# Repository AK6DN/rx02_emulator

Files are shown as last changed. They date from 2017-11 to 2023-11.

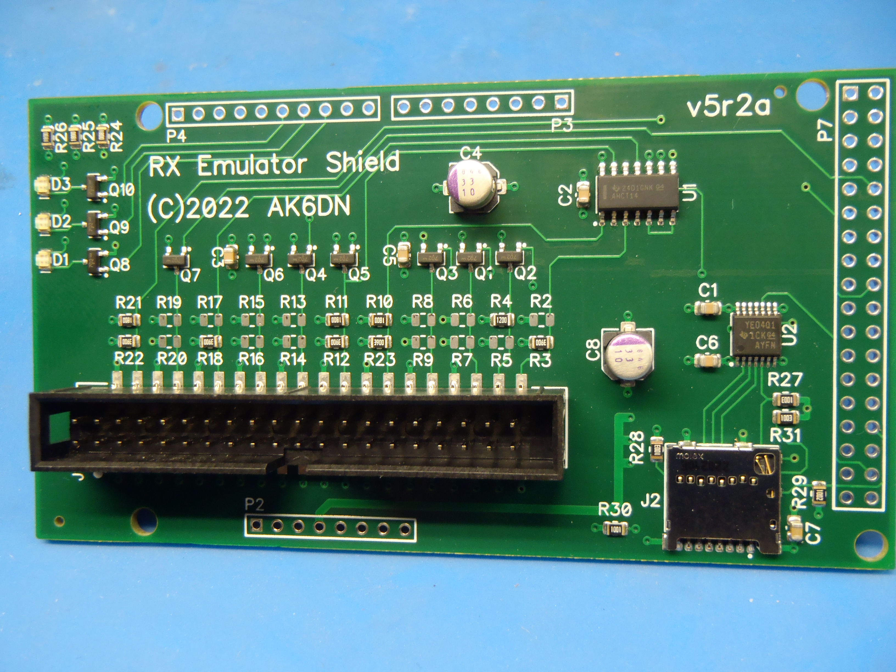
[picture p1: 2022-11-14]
documentation/pcb_v5_smt/rx02_emulator_pic.jpg

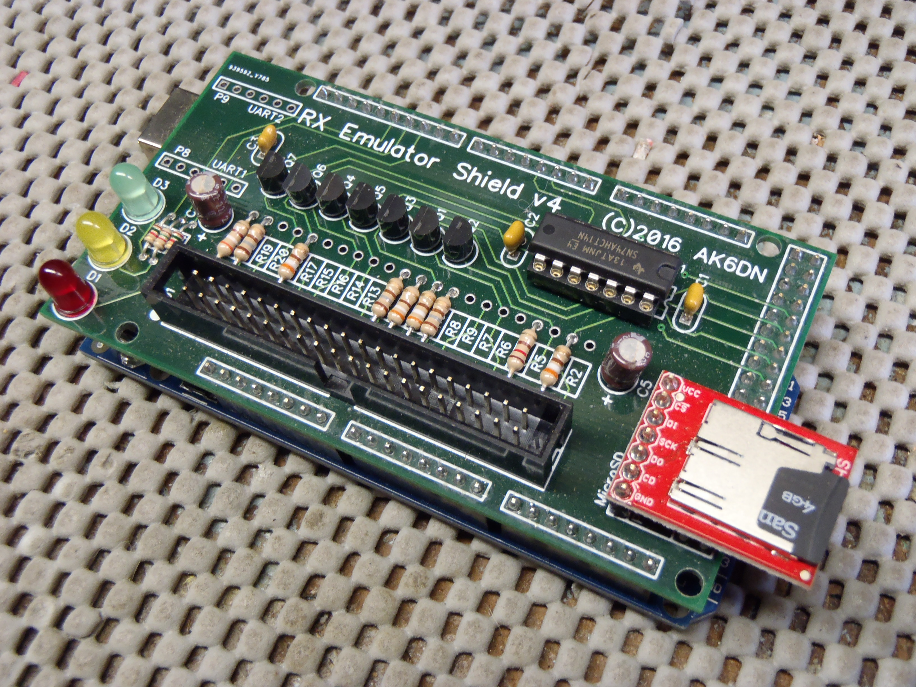
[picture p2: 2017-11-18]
documentation/pcb_v4_2n7k/rx02_emulator_pic.jpg

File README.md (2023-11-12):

# Overview #

`rx02_emulator` is a hardware/software emulation of a DEC RX02 (or RX01) dual 8" floppy disk drive. The software runs on an Arduino Mega2560 processor board with a custom hardware interface shield that maps a dozen or so digital port bits to the custom DEC RX drive interface protocol.

The emulator simulates two RX02/RX01 drives mapped to files on an attached MicroSD card.

This implementation was originally based on the design at:  http://www.chdickman.com/rx02/ but has been extensively modified for the Arduino and to provide the functionality necessary to pass the DEC RX02 hardware diagnostics.

Currently this design boots/runs under the PDP-11 XXDP and RT-11 operating systems and the PDP-8 OS/8 operating system.

The MicroSD card in the emulator is a FAT32 formatted filesystem, and it can be inserted (offline) into a WindowsPC to copy files to/from the device. By default, the files 'RX0.DSK' and 'RX1.DSK' are mapped to drive 0 and 1 on initialization.

Detection of single density media (256,256 bytes total) and double density media (512,512 bytes total) is done thru two differrent mechanisms. Files with the extension .RX1 will be forced to be single density, and resized appropriately (zero padded at the end, and truncated to size if required). Similarly files with the extension .RX2 will be forced to double density, and resized if necessary. Files with any other extension (ie, like .DSK) will be detected as single density if they are EXACTLY 256,256 bytes in size; and detected as double density if they are EXACTLY 512,512 bytes in size. Files that are other sizes will NOT be capable of being mounted until they are resized appropriately (the `E` and `F` commands can do this).

The emulator interfaces thru a simple ASCII terminal command line via the USB port on the Arduino device. After booting, typing: `H<cr>` types out the available commands. Below is a sample interaction showing the use of the `H`, `L`, `S` and `0` commands, and the debug level 1 log of what happens when `b dy0` is typed on the attached PDP-11/44 console terminal.

Startup configuration is saved in an ASCII text file SETUP.INI that contains user interface commands that are replayed on startup. The SETUP.INI file is written using the `W` command, and the current 0/1/Y/N/D/M/T options are saved in the file.

The hardware shield has three indicator LEDs:
<OL>
<LI>(RED) ON when INIT is asserted from the host or an error is detected in the emulator. OFF at command start.</LI>
<LI>(YEL) ON when the emulator is actively accessing the microSD card storage. OFF otherwise.</LI>
<LI>(GRN) ON when a command is inititated from the host, OFF when the command has completed (DONE set).</LI>
</OL>

Normal operation will see the GRN/YEL LEDs blinking rapidly or mostly ON. For non-storage commands (eg, buffer fill/empty) only GRN will be ON.

Hardware design files (schematics, PCB layout, BOM) are available in the documentation directory. Includes full schematic, PCB layout plots, and all gerbers.

The Arduino controller software has been moved into the source directory.

## Example ##

Sample boot log in the Arduino USB serial monitor window:
```
RX02 Emulator v2.02 (IDE 1.8.19/gcc 7.3.0) - Nov  3 2023 - 22:16:19
SD: libVersion=2.2.2
SD: cardType=SD3
SD: cardSize=3781MB
SD: volType=FAT32
SD: volBytesPerCluster=4096
SD: volClusterCount=964992
SD: volSizeBytes=3768MB
2016-09-24 18:02:14     512512 RX0.DSK
2016-09-27 15:06:44     512512 RX1.DSK
2020-04-01 00:00:26         50 SETUP.INI
2017-10-31 20:37:04     512512 RT11.RX2
2017-10-31 20:37:14     512512 OS8V3D.RX2
2016-10-24 11:31:02     256256 OS8V3Q.RX1
Valid MicroSD card detected.
RX: waiting for INIT to clear ... t=1154ms
RX: INIT has NOT cleared t=11155ms
RX: INIT rx_xmit_es(0244)

Processing setup file 'SETUP.INI' ...
0 RX0.DSK
Setting file[0]: 'RX0.DSK'
Y 0
Setting file[0] mode: R/W
1 RX1.DSK
Setting file[1]: 'RX1.DSK'
Y 1
Setting file[1] mode: R/W
D 1
Setting debug mode: 1 (Low)
M 2
Setting emulation mode: 2 (RX02+any)
T 0
Setting timing mode: 0 (Fastest)
S
Current file[0]: 'RX0.DSK' (R/W)
Current file[1]: 'RX1.DSK' (R/W)
... setup file processing complete!

Initialization complete.
H

Commands available:

  0 FILENAME    -- set unit 0 file to FILENAME; default RX0.DSK
                   file name 'none' (any case) for no disk present
  1 FILENAME    -- set unit 1 file to FILENAME; default RX1.DSK
                   file name 'none' (any case) for no disk present
  y(es) N       -- set unit N file read-write (default)
  n(o) N        -- set unit N file read-only
  m(ode) N      -- set emulation mode, 0=RX01+RX11, 1=RX01+RX8E, 2=RX02+any; default 2
  d(ebug) N     -- debug level, 0=none, 3=max; default 1
  t(iming) N    -- timing mode, 0=fast, 1=medium, 2=normal; default 0
                   0 as fast as possible; 2 simulates real RX02 drive
  r FILENAME    -- remove file FILENAME
  e FILENAME    -- extend/truncate file FILENAME to single density size
  f FILENAME    -- extend/truncate file FILENAME to double density size
  l(ist)        -- list all files on the SD card
  s(how)        -- show current unit filename assignments
  p(rint)       -- print full emulation state
  i(nit)        -- initialize emulator (like unibus INIT)
  k(ill)        -- kill the emulator (reset and restart, like reset button)
  w(rite)       -- write current configuration into the SETUP.INI file
  z(ap) STAMP   -- set current timestamp for file access
                   format is: YYYY-MM-DD HH:MM:SS or YYYY-MM-DD HH:MM
  h(elp)        -- display this text

Note: chars in () are optional. Case does not matter.

S
Current file[0]: 'RX0.DSK' (R/W)
Current file[1]: 'RX1.DSK' (R/W)
0 XXDP.DSK
Setting file[0]: 'XXDP.DSK'
W
Generating setup file 'SETUP.INI'

RX: waiting for INIT to clear ... t=49342ms
RX: INIT has cleared t=49438ms
RX: INIT rx_xmit_es(0244)

RX: cmd=0007
RX: RDSECT unit=0 den=S
RX: RDSECT sa=001
RX: RDSECT ta=001
RX: RDSECT rx_xmit_es(0060)

RX: waiting for INIT to clear ... t=49462ms
RX: INIT has cleared t=49557ms
RX: INIT rx_xmit_es(0244)

RX: cmd=0407
RX: RDSECT unit=0 den=D
RX: RDSECT sa=001
RX: RDSECT ta=001
RX: RDSECT pos=6656. len=256.
RX: RDSECT rx_xmit_es(0040)

RX: cmd=0403
RX: EMPBUF unit=0 den=D
RX: EMPBUF wc=200
RX: EMPBUF rx_xmit_es(0000)

RX: cmd=0407
RX: RDSECT unit=0 den=D
RX: RDSECT sa=003
RX: RDSECT ta=001
RX: RDSECT pos=7168. len=256.
RX: RDSECT rx_xmit_es(0040)

RX: cmd=0403
RX: EMPBUF unit=0 den=D
RX: EMPBUF wc=200
RX: EMPBUF rx_xmit_es(0000)

...
```

## Notes ##

(1) This code has been written with the assumption that `Xprintf` support has been added to the PRINT class in the Arduino development environment.

(2) This code uses the SDfat library available at:  https://github.com/greiman/SdFat

(3) This code was written with tap stops set at 4 (versus the default of 2). Manually edit the Arduino <B>preferences.txt</B> file tab size line to be: <B>editor.tabs.size=4</B> if desired.

# ALTERNATIVE to ARDUINO IDE #

For those not interested in the source and/or installing the full Arduino IDE environment and tweaking it as necessary, I have now added a precompiled .hex version of the code representing the state of the current source. It is located in the 'binary' folder. There are two versions, without and with the bootloader image present. In most cases you would want to use the version of the .hex without the bootloader as the bootloader is already present (and required to be working) in any purchased ArduinoMEGA2560 board.

There are at least two methods to download a .hex image file to the Arduino (and I am sure there are more):

(1) Using `avrdude` in command line mode. This is the way the Arduino IDE does it when you install the IDE and use it to download the compiled .hex file. You can use the installed version of avrdude to do the download, or alternatively if you don't want to install the full IDE and compile from source, you can download the avrdude program directly from here: https://github.com/avrdudes/avrdude 

On the command line:
```
  avrdude -D -cwiring -pm2560 -b115200 -PCOM# -Uflash:w:rx02_emulator.ino.hex:i
```
where `COM#` is the port that is associated with your mega2560 Arduino board, and other options that you may desire. Refer to the avrdude documentation.

(2) Using a program called `xLoader` that is available from here: https://github.com/binaryupdates/xLoader . It is a simple Windows standalone application. 

The process to download the .hex image using xLoader is documented here: https://www.aranacorp.com/en/generating-and-uploading-hex-files-to-an-arduino/ 

# INSTALLATION #

The following sections detail the installation and configuration of the Arduino software environment, getting the `rx02_emulator` code, compiling it, and downloading it to a target board.

## Arduino IDE ##

If you don't have the Arduino development environment installed on your system, the first step is to download and install it. Go to:

https://www.arduino.cc/

and click on the `Software` tab to get to the download page.

Scroll down to the `Download the Arduino IDELegacy IDE (1.8.X)` section and download the installer appropriate for your system. All development and testing to data has been with the legacy 1.X IDE. I have done nothing with the newer 2.X IDE, so if you want to use that you are on your own.

Update: I have installed the IDE 2.2.1 alongside my existing IDE 1.8.19. They live in separate directories so can be simultaneously installed. They share library and board file definitions, so I was able to launch IDE 2.2.1 and recompile and download the existing design done under IDE 1.8.19 with no errors. So the changes below for adding printf support and installing the SDFAT (and optional TIMELIB) libraries should take place following the existing instructions. One anomaly is after the compile the Arduino IDE version reported is IDE 1.6.7, when one might expect it to be IDE 2.2.1. This is a 'bug' reported in github and it appears the Arduino developers don't seem to feel it makes a difference and are reluctant to change it. So just be warned about the somewhat bogus report the program was compiled under IDE 1.6.7 when it appears in the compiled code welcome message.

Run the install.

## SD FAT Library ##

The emulator software requires a third party SD card FAT filesystem access library. Go to:

https://github.com/greiman/SdFat

On the right hand side of the page there is a `Clone or download` green button; click it and select `Download ZIP` and save the file. It will likely be named `SdFat-master.zip`.

Unzip the contents of `SdFat-master.zip` into a folder. There should be a folder inside the top level folder named `SdFat`.

Move the folder `SdFat` into your Arduino local library folder. On Windows, this would be into the folder:

```
C:\Users\yourname\My Documents\Arduino\libraries
```

which probably just contains a `readme.txt` file. The `SdFat` library is now installed and ready for use.

As of version v1.96 release the code is compatible with either the existing v1 SDfat library (eg, v1.1.4) or the newer v2 SDfat library (eg, v2.2.0) code.

I have tested with the v2.0.6, v2.0.7, v2.1.0, and v2.2.0 SDfat libraries. There were some changes from 2.0.x to 2.1.x and later and these are accounted for in some conditionals.

## PRINTF Configuration ##

The emulator code is written assuming that the printf/sprintf methods have been added to the serial I/O and file access routines. The default Arduino install does not have this support so it needs to be configured.

The following page:

http://playground.arduino.cc/Main/Printf

describes several ways to do this; the preferred method I suggest is described under `Adding printf() to Print class`.

It is not difficult, but does require editing a standard Arduino system file and adding some code.

On windows, the target file to be modified is:

```
%ProgramFiles(x86)%\Arduino\hardware\arduino\avr\cores\arduino\Print.h
```

the following code:

```
#include <stdarg.h>
#define PRINTF_BUF 80 // define the tmp buffer size (change if desired)
   void printf(const char *format, ...)
   {
   char buf[PRINTF_BUF];
   va_list ap;
        va_start(ap, format);
        vsnprintf(buf, sizeof(buf), format, ap);
        for(char *p = &buf[0]; *p; p++) // emulate cooked mode for newlines
        {
                if(*p == '\n')
                        write('\r');
                write(*p);
        }
        va_end(ap);
   }
#ifdef F // check to see if F() macro is available
   void printf(const __FlashStringHelper *format, ...)
   {
   char buf[PRINTF_BUF];
   va_list ap;
        va_start(ap, format);
#ifdef __AVR__
        vsnprintf_P(buf, sizeof(buf), (const char *)format, ap); // progmem for AVR
#else
        vsnprintf(buf, sizeof(buf), (const char *)format, ap); // for the rest of the world
#endif
        for(char *p = &buf[0]; *p; p++) // emulate cooked mode for newlines
        {
                if(*p == '\n')
                        write('\r');
                write(*p);
        }
        va_end(ap);
   }
#endif
```

needs to be added near the end of the file, just prior to the second to last non blank line:  `};`

NOTE this change must be made ANY TIME a new version of the Arduino IDE is installed, as the new install will overwrite the change to the `Print.h` file. In most recent Arduino upddates (since 1.6.X at least) the `Print.h` file has not changed, so a copy of the updated file can be squirreled away to save some time in the update process. Note that there was a minor change to the base `Print.h` file as of Arduino IDE 1.8.2 (this change should be integrated in the updated Print.h file as well).

At this point the Arduino IDE should be fully setup for use in compiling the emulator software.

Under the `Preferences` menu, I find ticking the `Show verbose output` `compilation` and `upload` boxes to be useful.

I also recommend checking the `Verify code after upload` box in the same dialog.

## RX02 Emulator ##

To download the RX02 emulator Arduino software, go to:

https://github.com/AK6DN/rx02_emulator

and (like in the library download) click the `Clone or download` green button on the right side of the page, select `Download ZIP`, and save the file. It will likely be named `rx02_emulator-master.zip`.

Unzip the contents into a folder, it will likely end up being named `rx02_emulator-master`. You must rename it to `rx02_emulator` as the Arduino IDE requires the outer level folder name match the project name (which is `rx02_emulator.ino`).

## Compiling ##

You should now be able to launch the Arduino IDE by going into the `source/rx02_emulator` folder and double clicking on the top level design file `rx02_emulator.ino`.

Before compiling you need to select the board and processor type.

Under the `Tools` menu select `Board:` and validate it is: `Arduino/Genuino Mega or Mega 2560`

Under the `Tools` menu select `Processor:` and validate it is: `ATmega2560`

You should now be able to, under the `Sketch` menu, select `Verify/Compile` (or type `CTRL-R`) to compile.

There should be no errors flagged if the SDfat library was installed correctly, the printf mod was performed, and the board and processor type have been configured correctly.

## Uploading ##

After verifying the compile you are now ready to be able to upload the code to your board.

NOW plug your Arduino Mega2560 board into a USB port on your system and wait for the USB driver to install.

When done, go to the `Tools` menu (again) and select the `Port:` entry to correspond to the USB serial port your board has been configured as.

You should now be able to select menu `Sketch` then `Upload` (or type `CTRL-U`) to upload the code to your board.

## Running ##

After a successful upload, your Arduino should start running immediately. To get access to the menu window, select under the `Tools` menu the `Serial Monitor` item (or type `CTRL-SHIFT-M`).

You will need to configure the baud rate / line ending of the monitor window before you can see output and type input.

In the lower right of the window, select the maximum baud rate `250000 baud` that the Arduino supports over USB. This minimizes the impact of the debug output window on performance, and the emulator software selects this rate by default. As of emulator code v1.8 and Arduino IDE 1.8.2 or later it is possible to enable higher debug window baud rates (500Kb, 1Mb, or 2Mb) but not all Arduino Mega2560 boards may support these rates 100% reliably. You will have to test your board individually to see if a higher baud rate can be enabled.

In the lower right, select `Carriage Return` line ending, so when you type in the text box at the top of the window, and then click `SEND` a `CR` character will be appended to the end of the string.

At this point you should be seeing debug output in the serial monitor window, and be able to send menu commands to it.

## Validation ##

Testing to date has been performed with a UNIBUS PDP-11/44 with each of an RX211 and an RX11, a UNIBUS PDP-11/34A with each of an RX211 and an RX11, and an OMNIBUS PDP-8m with an RX8E/RX28 so RX01/RX8E and RX02/RX28 configurations can be tested. I do not have access to RXV11 or RXV21 boards for testing (nor do I have an QBUS systems). Users have tested the emulator with QBUS RXV21 and RXV11 and provided positive feedback.

I have personally tested and validated the following confgurations:

```
PDP-11/44 with M8256 RX211 ... ZRXFB0 RX211/RX02 Functional Test  ........ PASS
                               ZRXDC0 RX211/RX02 Performance Exerciser ... PASS
                               XXDPv25 DY boots and runs ................. PASS
                               RT-11v5.7 DY boots and runs ............... PASS
                               RX02WR and RX02RD home grown diagnostics .. PASS

PDP-11/34A with M8256 RX211 .. ZRXFB0 RX211/RX02 Functional Test  ........ PASS
                               ZRXDC0 RX211/RX02 Performance Exerciser ... PASS
                               XXDPv25 DY boots and runs ................. PASS
                               RT-11v5.7 DY boots and runs ............... PASS
                               RX02WR and RX02RD home grown diagnostics .. PASS

PDP-11/44 with M7846 RX11 .... ZRXBF0 RX11/RX01 Functional Test .......... PASS
                               ZRXAF0 RX11/RX01 Performance Exerciser .... PASS
                               RT-11v5.3 DX boots and runs ............... PASS

PDP-11/34A with M7846 RX11 ... ZRXBF0 RX11/RX01 Functional Test .......... tbd
                               ZRXAF0 RX11/RX01 Performance Exerciser .... tbd
                               RT-11v5.3 DX boots and runs ............... tbd

PDP-8m with M8357 RX8E/RX01 .. OS8v3Q boots and runs ..................... PASS
                               RXTEST home grown diagnostic .............. PASS

PDP-8m with M8357 RX28/RX02 .. OS8v3D boots and runs ..................... PASS
                               RXTEST home grown diagnostic .............. PASS
```

Other users have supplied the following test results:

```
PDP-11/34 with M7846 RX11 .... ZRXBF0 RX11/RX01 Functional Test .......... PASS (thunter0512)
                               ZRXAF0 RX11/RX01 Performance Exerciser .... PASS (thunter0512)
```

## Hardware ##

UPDATED 09-Aug-2021 -- the timing macros for the data transfer to/from the interface board have been modified to allow working with a longer flat cable. As of the v1.95 release the emulator has been tested and worked flawlessly using a DEC BC06R-12 cable (12' long, about 4m) on a PDP-11/44 with an RX211 interface. Performance degradation due to the slightly slower data transfer handshake timing has been measured at about 5% or less, which in practice is not noticeable. Of course it still works flawlessly using a shorter 0.5 to 1.5m cable as well.

DEPRECATED 09-Aug-2021 -- Many original RX01/2 configurations come with an up to 5m controller card to connector cable (a 40p flat cable with 2x20p IDE connectors). It has been noticed that in some configurations using this same cable to connect to the RX02 emulator from the RXnn controller card results in unreliable operation or it does not work at all. The recommendation is to use a shorter 40p flat cable, on the order of 0.5m to 1.5m at most, for reliable operation.

## The End ##

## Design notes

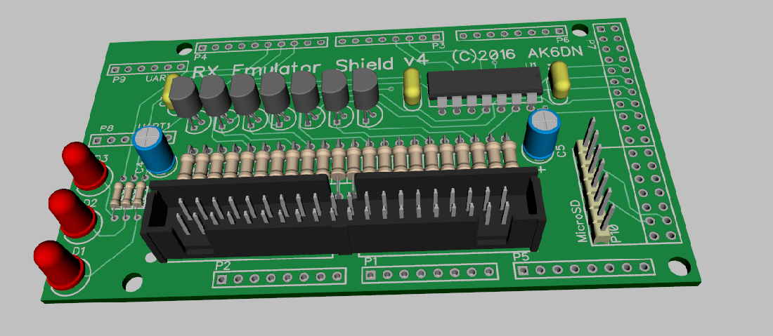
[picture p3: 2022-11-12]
documentation/pcb_v4_2n7k/rx02_emulator_3dv.png

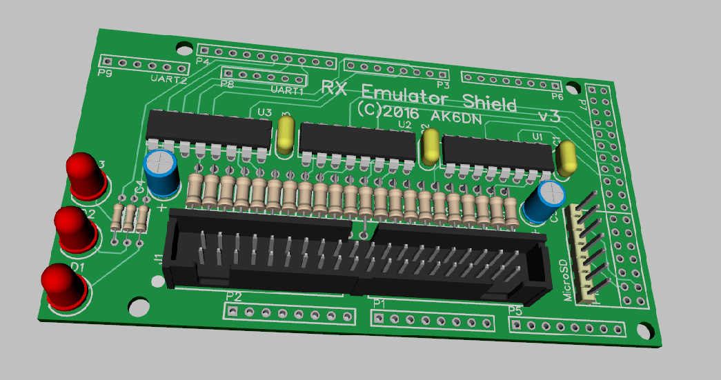
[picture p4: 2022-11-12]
documentation/pcb_v3_8641/rx02_emulator_3dv.png

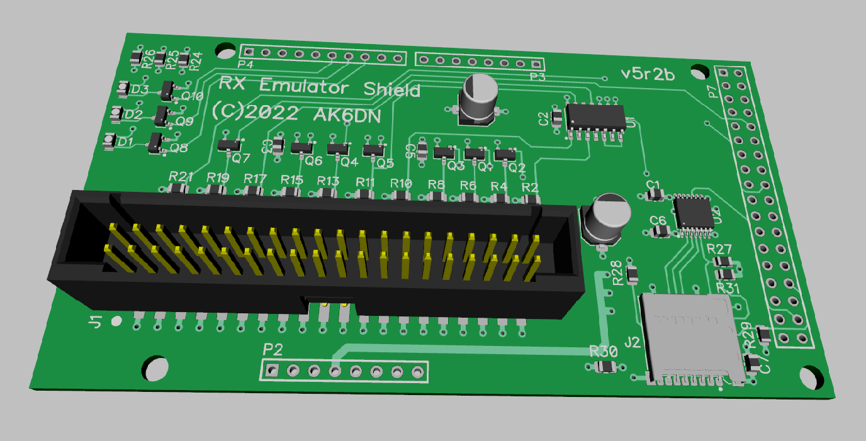
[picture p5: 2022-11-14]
documentation/pcb_v5_smt/rx02_emulator_3dv.png

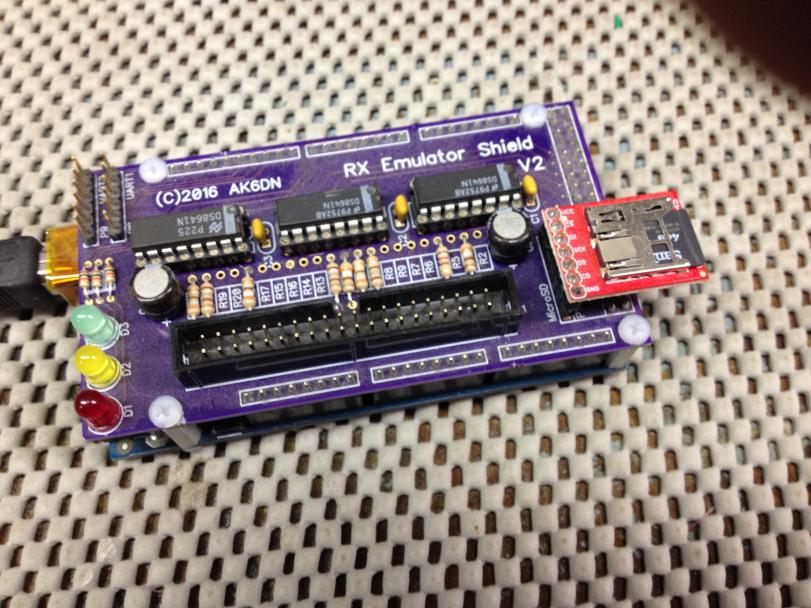
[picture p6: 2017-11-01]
documentation/pcb_v3_8641/rx02_emulator_pic.jpg

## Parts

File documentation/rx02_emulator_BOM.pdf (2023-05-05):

rx02_emulator_BOM

05/05/2023

Assembly Order | Quantity | Reference | Side | Note | Description | Manufacturer | ManufacturerPN | DigikeyPN
1 | 3 R24,R25,R26 | Top | - | 1Kohm,1/8W resistor (for 2mA LED current; value appropriate to LED) | Stackpole | CF18JT1K00 | CF18JT1K00CT-ND
2 | 5 R3,R12,R18,R22,R23 | Top | - | 390ohm,1/4W resistor | KOA Speer | CF1/4CT52R391J | 2019-CF1/4CT52R391JCT-ND
3 | 3 R10,R11,R21 | Top | - | 180ohm,1/4W resistor | KOA Speer | CF1/4CT52R181J | 2019-CF1/4CT52R181JCT-ND
4 | 1 R4 | Top | - | 120ohm,1/4W resistor | KOA Speer | CF1/4CT52R121J | 2019-CF1/4CT52R121JCT-ND
5 | 1 U1 | Top | - | 14p 300mil DIP socket | Assman | A 14-LC-TT | AE9989-ND
6 | 3 C1-C3 | Top | - | 100nF/16V ceramic capacitor, 100mil spacing | Vishay | K104K10X7RF53L2 | BC5137-ND
7 | 7 Q1-Q7 | Top | - | 2N7000 transistor, TO-92 package | Onsemi | 2N7000BU | 2N7000BU-ND
8 | 1 J1 | Top | - | 20x2P 100mil male box header | Sullins Connector | SBH11-PBPC-D20-ST-BK | S9175-ND
9 | 1 D1 | Top | - | LED, RED, 5mm diameter, 100mil spacing | Broadcom | HLMP-4700 | 516-1325-ND
10 | | 1 D2 | Top | - | LED, YEL, 5mm diameter, 100mil spacing | Broadcom | HLMP-4719 | 516-1326-ND
11 | | 1 D3 | Top | - | LED, GRN, 5mm diameter, 100mil spacing | Broadcom | HLMP-4740 | 516-1327-ND
12 | | 2 C4,C5 | Top | - | 33uF/16V electrolytic capacitor, radial, 100mil spacing, 6mm max diameter | Panasonic | ECE-A1CKS330 | P968-ND
13 | | 1 P4 | Bottom | - | 10x1P 100mil male header, 0.230/0.120 pin length, breakaway strip | Sullins Connector | PRPC040SAAN-RC | S1011EC-40-ND
14 | | 2 P2,P3 | Bottom | - | 8x1P 100mil male header, 0.230/0.120 pin length, breakaway strip | ref item 13 | - | -
15 | | 1 P7 | Bottom | - | 18x2P 100mil male header, 0.230/0.120 pin length, breakaway strip | Sullins Connector | PRPC018DAAN-RC | S2011EC-18-ND
16 | | 1 P10 | Top | - | 7x1P 100mil male header, 0.230/0.120 pin length, breakaway strip | ref item 13 | - | -
17 | | 1 P10 | Top | - | microSD breakout board | AK6DN | - | -
18 | | 1 U1 | Top | - | 74HCT/AHCT14 hex schmitt inverter (or HC/AHC14) | Texas Instruments | SN74AHCT14N | 296-4674-5-ND
- | | 3 P1,P5,P6 | Bottom | NOSTUFF | 8x1P 100mil male header, 0.230/0.120 pin length, breakaway strip | - | - | -
- | | 2 P8,P9 | Top | NOSTUFF | 6x1P 100mil male header, 0.230/0.120 pin length, breakaway strip | - | - | -

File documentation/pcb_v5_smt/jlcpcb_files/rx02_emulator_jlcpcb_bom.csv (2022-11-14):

Comment | Designator | JLCPCB Part # | Cost | Stock
CL21B104KBFNNNE | C1, C2, C3, C5, C6, C7 | C136621 | 0.01 | 35387
10SVP33M | C4, C8 | C347572 | 0.51 | 1251
LTST-C170KRKT | D1 | C94868 | 0.02 | 100
LTST-C170KSKT | D2 | C125091 | 0.02 | 100
LTST-C170KGKT | D3 | C98221 | 0.02 | 100
321040MG0CBK00A01 | J1 | C601975 | 0.19 | 772
104031-0811 | J2 | C585350 | 0.53 | 5903
2N7002LT1G | Q1, Q2, Q3, Q4, Q5, Q6, Q7,Q8,Q9,Q10 | C16338 | 0.05 | 5825
AC0805FR-07180RL | R10,R11,R21,R24,R25,R26 | C228347 | 0.01 | 245
AC0805FR-071KL | R30 | C140870 | 0.01 | 31619
AC0805FR-07100KL | R27,R28,R31 | C144587 | 0.01 | 2268
AC0805FR-0710KL | R29 | C140868 | 0.01 | 329825
AC0805FR-07390RL | R3,R12,R18,R22,R23 | C228782 | 0.01 | 26920
AC0805FR-07120RL | R4 | C228277 | 0.01 | 15312
SN74AHCT14DR | U1 | C141316 | 0.16 | 2690
TXB0104QPWRQ1 | U2 | C527571 | 0.88 | 3551

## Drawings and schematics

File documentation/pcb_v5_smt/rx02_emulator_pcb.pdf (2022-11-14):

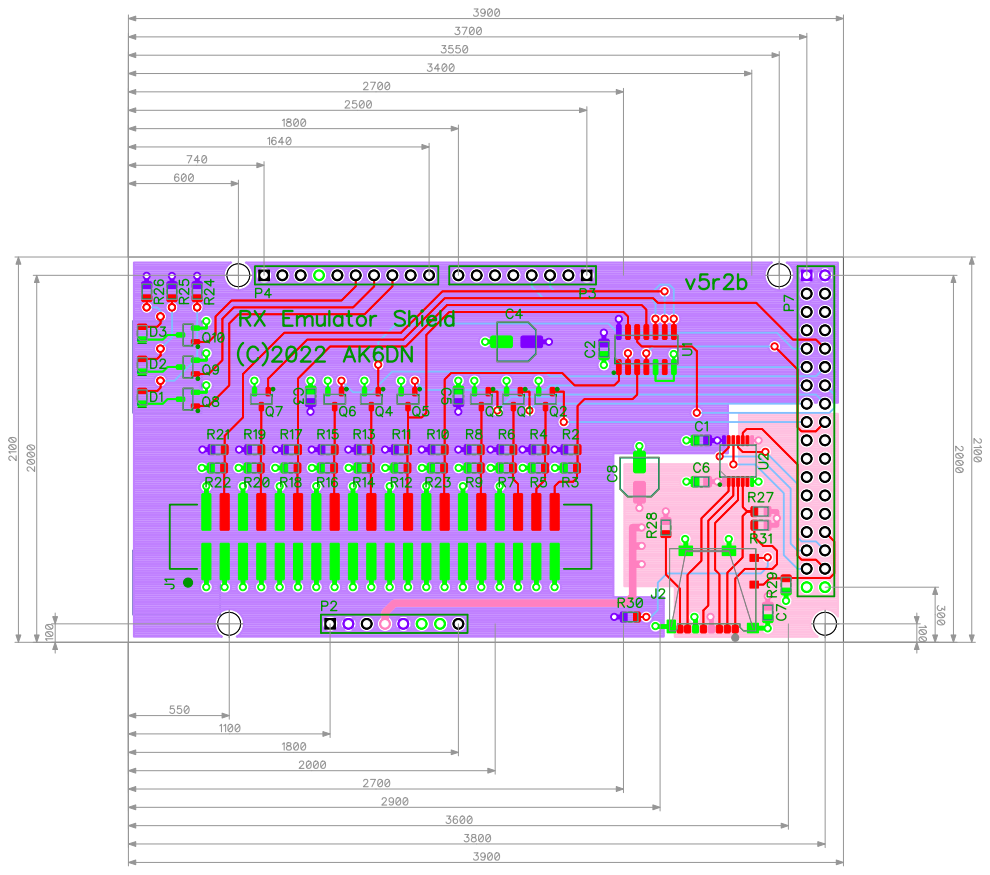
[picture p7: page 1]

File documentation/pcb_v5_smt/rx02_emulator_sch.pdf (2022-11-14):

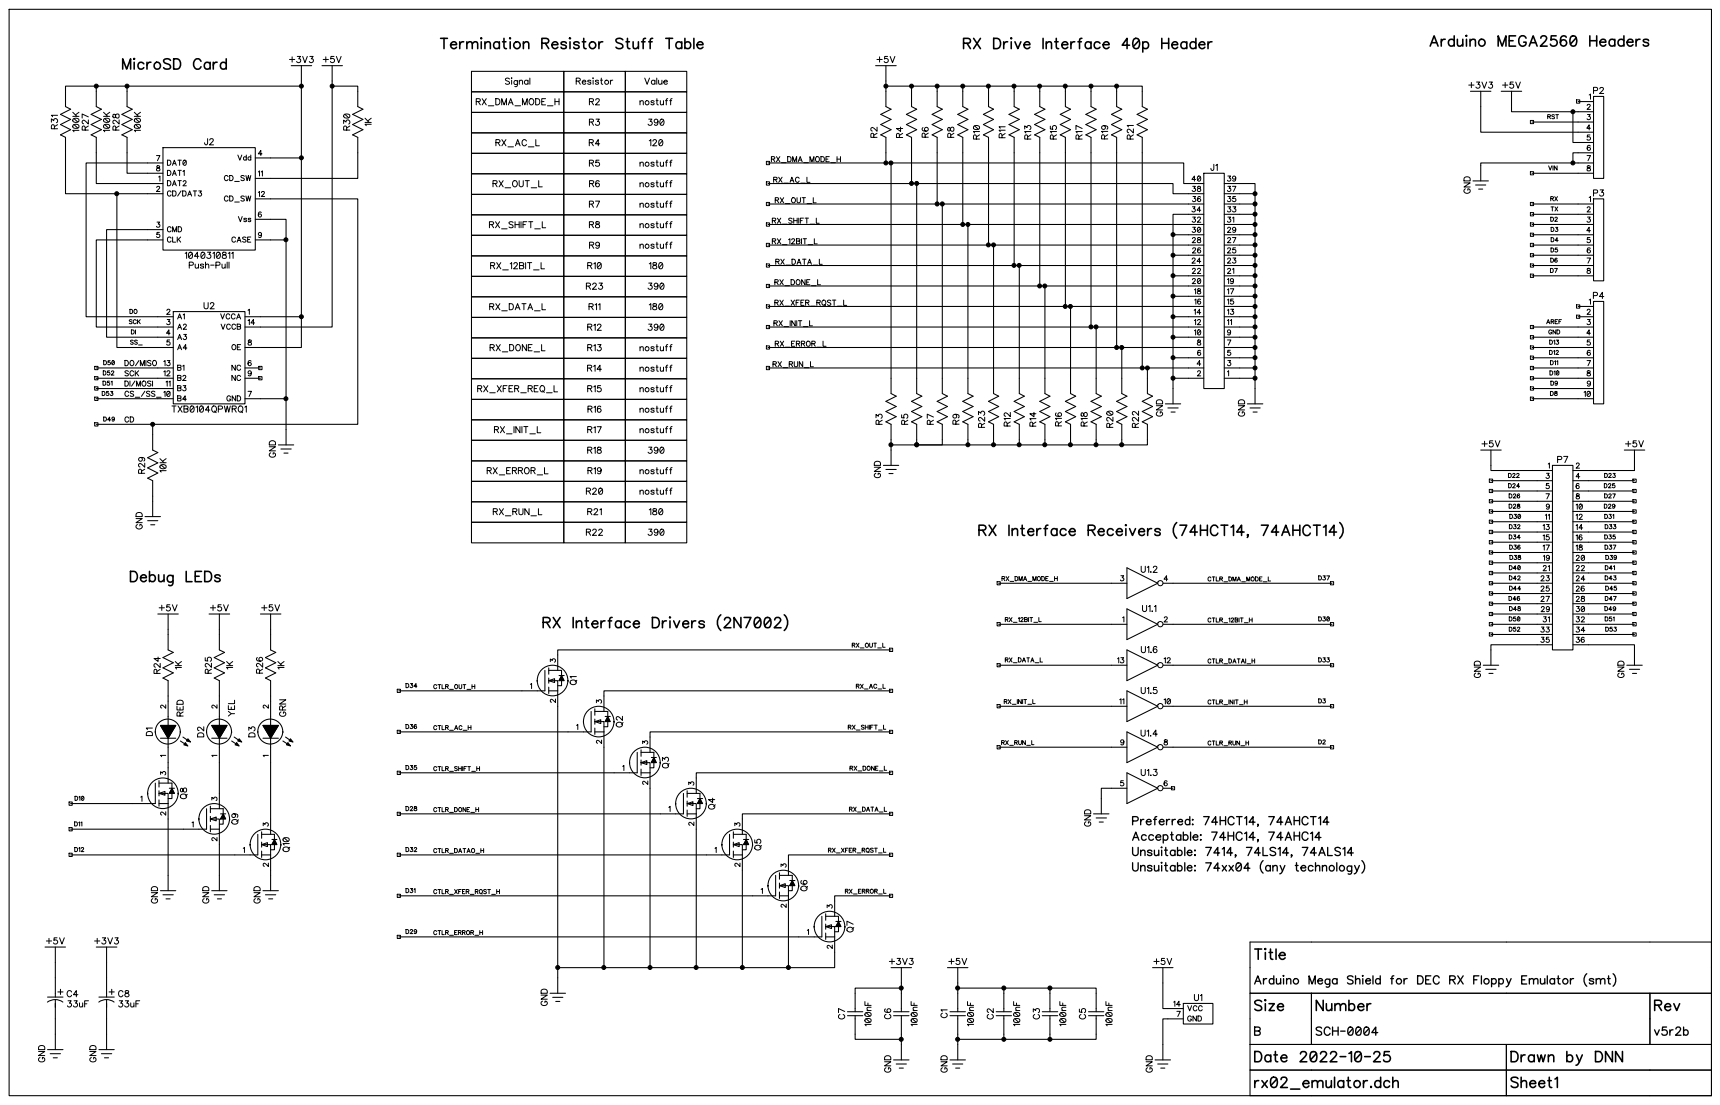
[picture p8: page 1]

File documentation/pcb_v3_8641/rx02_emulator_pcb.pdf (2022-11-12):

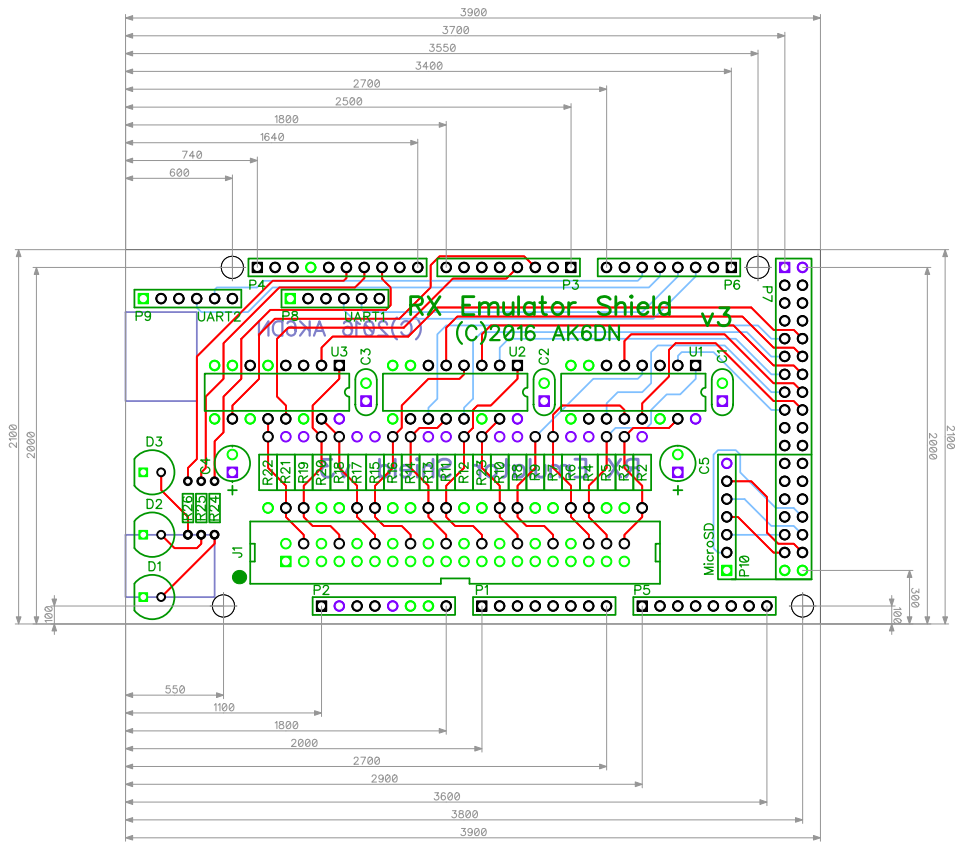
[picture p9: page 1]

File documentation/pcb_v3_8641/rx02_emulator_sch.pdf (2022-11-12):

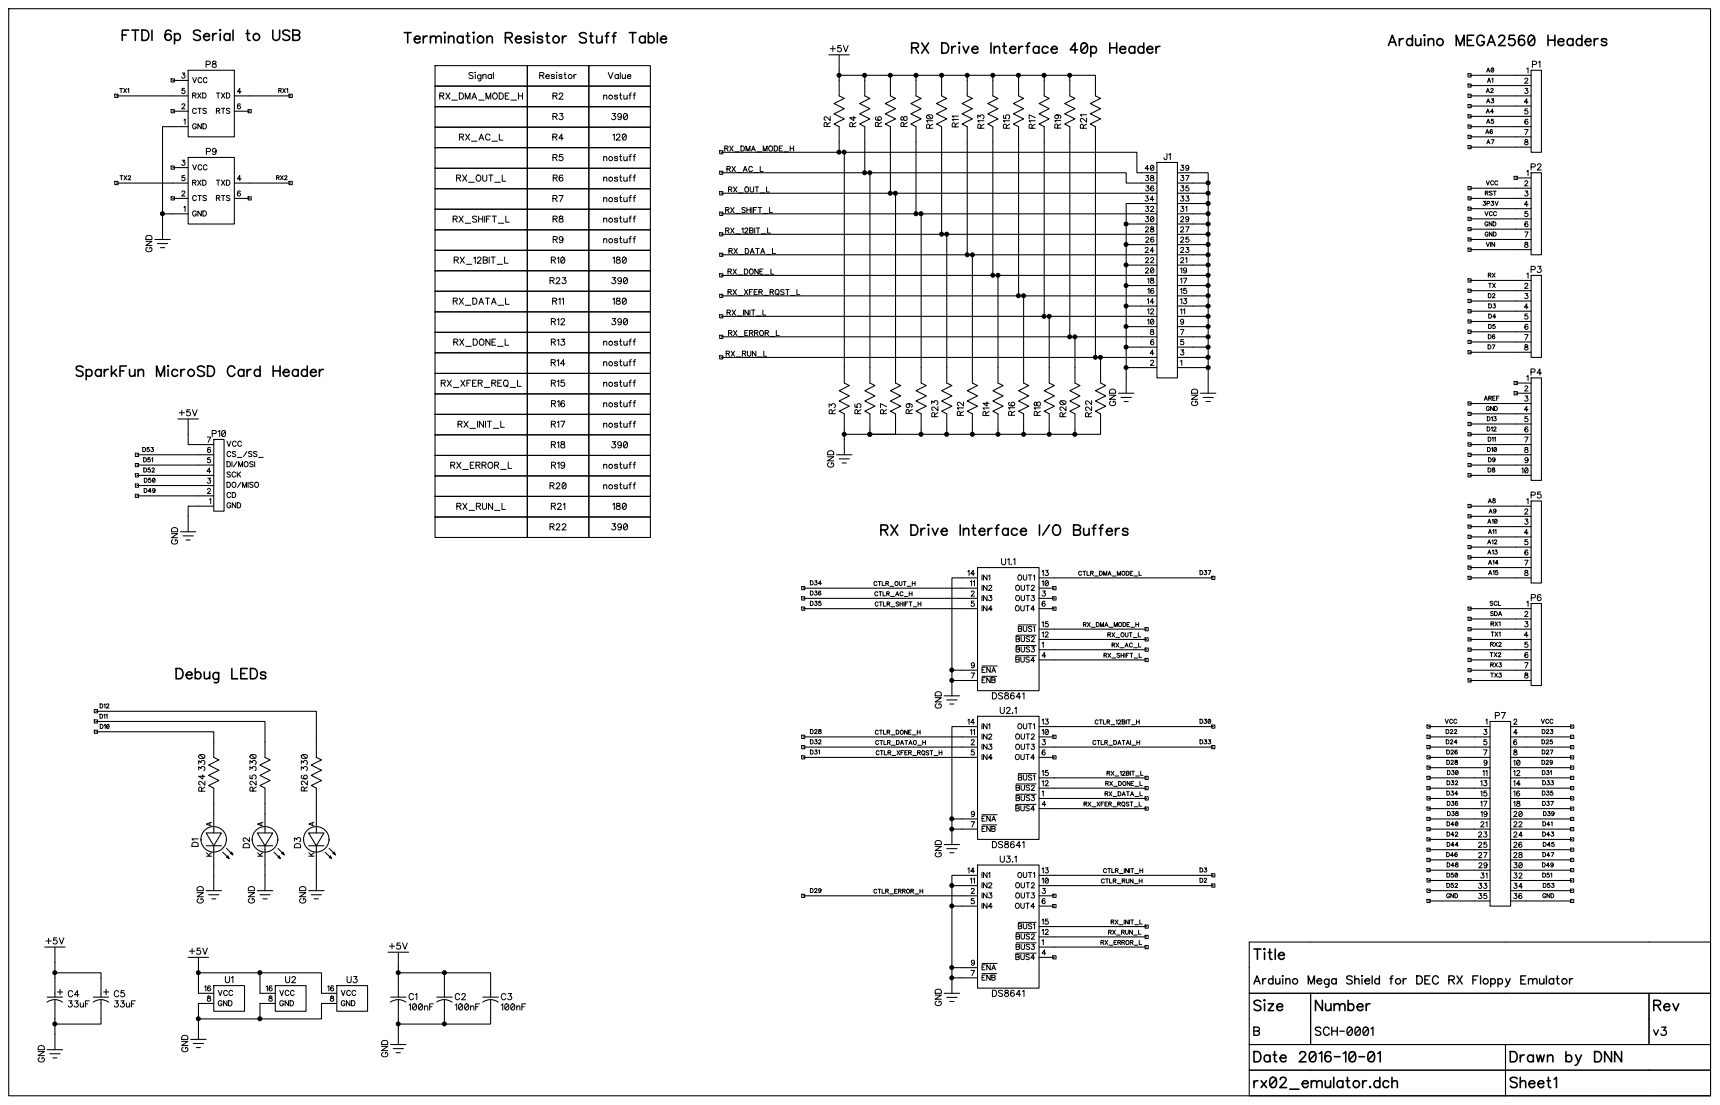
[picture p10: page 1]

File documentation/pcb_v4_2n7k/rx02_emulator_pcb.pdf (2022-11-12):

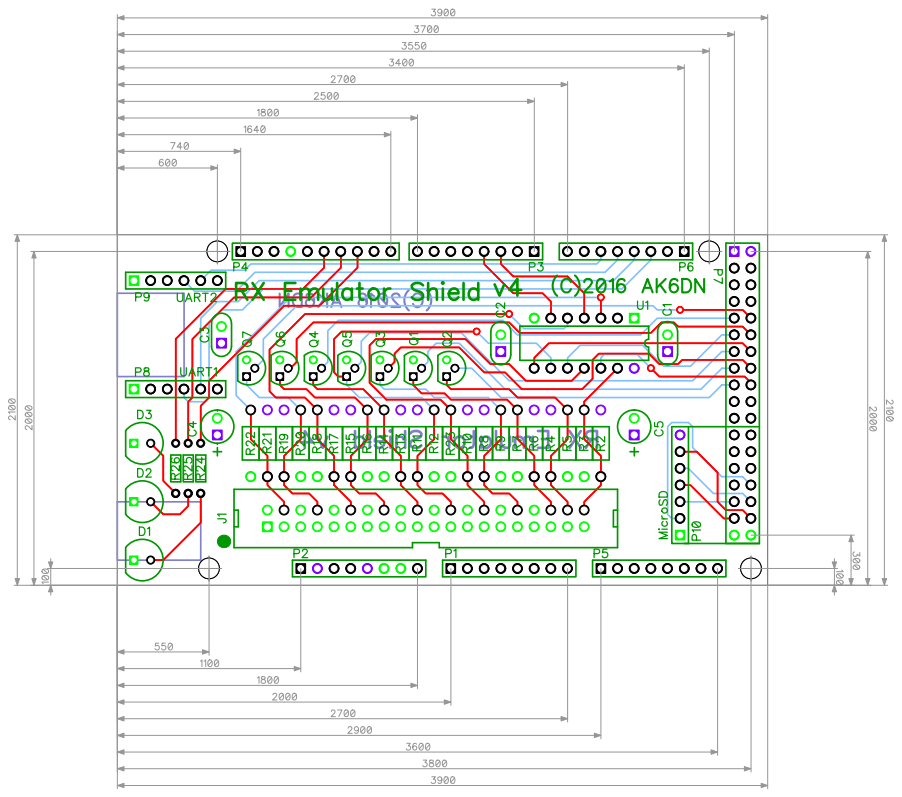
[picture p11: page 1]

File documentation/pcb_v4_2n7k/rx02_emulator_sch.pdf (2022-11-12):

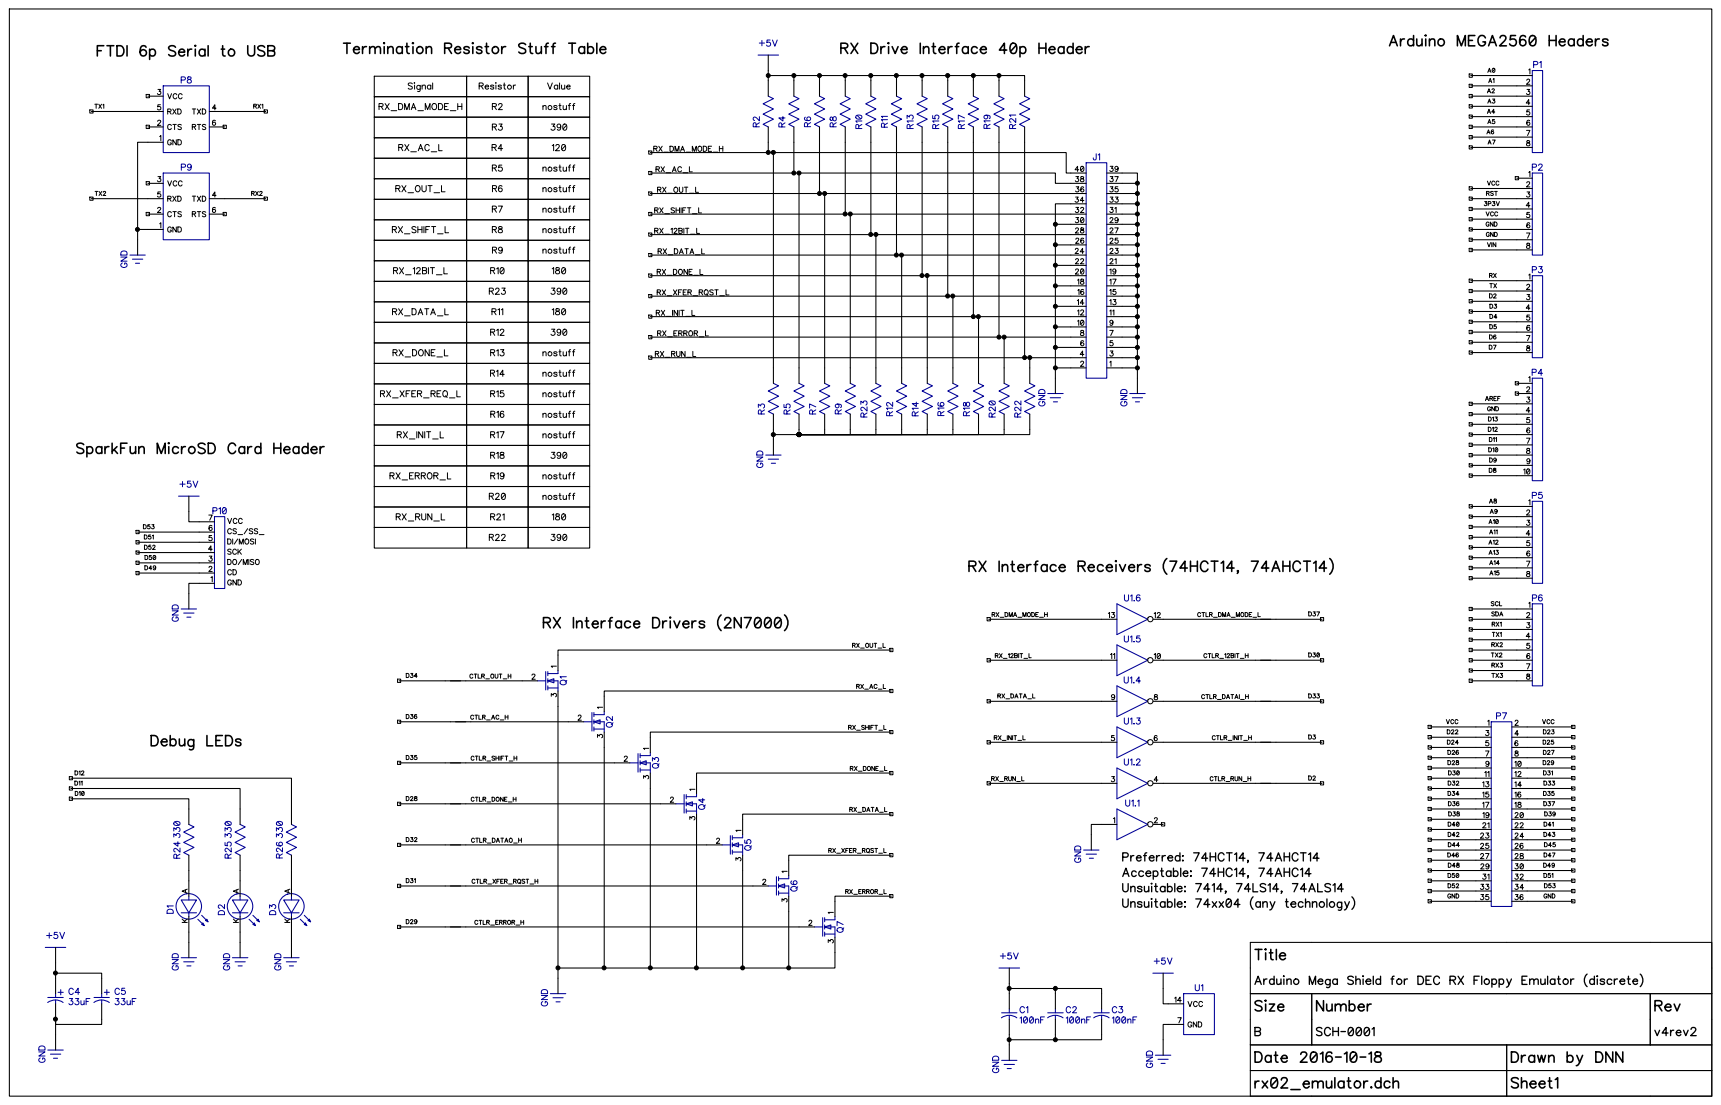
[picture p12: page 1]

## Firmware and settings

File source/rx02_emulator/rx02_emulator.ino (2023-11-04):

//
// RX8E/RX28/RX11/RX211/RXV11/RXV21 Interface to RX01/RX02 Drive Emulator with microSD Card Storage
//
// Copyright (c) 2015-2023, Donald N North
//
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
// Except as contained in this notice, the name of Donald N North shall not be
// used in advertising or otherwise to promote the sale, use or other dealings
// in this Software without prior written authorization from Donald N North.
//
// 22-Aug-2015 donorth Initial version
//

//
// definitions
//
#define USE_RX     1
#define TEST_RX    0
#define DEBUG_RX   1
//
#define USE_SD     1
#define TEST_SD    0
#define DEBUG_SD   1

// program version id
#define VERSION  "v2.02"

// baud rate for USB serial debug port
//
//   250Kb is highest that AVR Mega2560/16U2 combo can run (ArduinoIDE 1.8.1 or earlier)
//   2000Kb is the highest that AVR Mega2560/16U2 combo can run (ArduinoIDE 1.8.2 or later)
//
//   All 'genuine' Arduino Mega2560s use this combo, so should work ok.
//
//   Mega2560 'clone' boards NOT using the 16U2 as a USB/Serial interface
//   may have issues running at this rate. Boards will have to be tested.
//   On some of these boards 230.4K or 115.2K may be the highest possible
//   rate possible. This will have an impact if using any 'debug' mode.
//
//   Depending upon the Mega2560 board, 2Mb or 1Mb may not even work 100%
//   reliably, so if enabling those modes you must test your Arduino board
//   to see if it performs as you expect (the L command is a good test).
//
#if ARDUINO >= 10802
// IDE 1.8.2 and later enable 500Kb, 1Mb, and 2Mb baud rates.
//#define SERIAL_BAUD_RATE 2000000L
//#define SERIAL_BAUD_RATE 1000000L
//#define SERIAL_BAUD_RATE  500000L
#define SERIAL_BAUD_RATE  250000L
#else
// IDE 1.8.1 and earlier 250Kb is the max baud rate.
#define SERIAL_BAUD_RATE  250000L
#endif



//
// includes
//
#include "my_project.h"
#include "led_driver.h"
#include "rx02_driver.h"
#include "sdcard_driver.h"



//
// global routine definitions
//
void (*resetFunc) (void) = 0; // declare reset function at address 0



//
// global variables
//
HardwareSerial *tty = &Serial; // optionally &Serial1 or &Serial2 for other UART connectors

char setup_filename[] = "SETUP.INI";



#if TEST_SD
//
// SD card file access test
//
void sd_test (void)
{
    uint8_t wrdata[] = { 0, 1, 2, 3, 4, 5, 6, 7, 8, 9, 10, 11, 12, 13, 14, 15 };
    uint8_t wrorder[] = { 2, 1, 3, 0, 5, 4 };
    uint8_t rddata[16];
    uint8_t rdorder[] = { 5, 4, 3, 2, 1, 0 };
    char name[] = "TEST1.DSK";
    uint32_t pos;
    uint16_t num;
    uint16_t len;
    uint16_t cnt;
    uint8_t  i;

    tty->printf("\n========================================\n");

    tty->printf("\nSDtest removing test file: %s\n", name);
    sd_remove_file(name);
    sd_list_files(tty);

    pos = sizeof(wrorder)*sizeof(wrdata);
    tty->printf("\nSDtest setting file size to %lu.\n", pos);
    tty->printf("  file size is %lu. bytes\n", sd_set_file_size(name, pos, SD_POS_AT_BEGIN));

    for (cnt = 0; cnt < sizeof(wrorder); ++cnt) {
        len = sizeof(wrdata);
        pos = len*wrorder[cnt];
        tty->printf("\nSDtest (%d) writing test file, %u. bytes at offset %lu.\n", cnt, len, pos);
        for (i = 0; i < sizeof(wrdata); ++i) { wrdata[i] = (wrdata[i] & 0xF) | (wrorder[cnt]<<4); }
        num = sd_write_bytes(name, pos, wrdata, len);
        tty->printf("  wrote %u. bytes\n", num);
        tty->printf("  file size is %lu. bytes\n", sd_get_file_size(name));
    }

    tty->printf("\nSDtest getting file size\n");
    pos = sd_get_file_size(name);
    tty->printf("  file size is %lu. bytes\n", pos);

    for (cnt = 0; cnt < sizeof(rdorder); ++cnt) {
        len = sizeof(rddata);
        pos = len*rdorder[cnt];
        tty->printf("\nSDtest (%d) reading test file, %u. bytes at offset %lu.\n", cnt, len, pos);
        num = sd_read_bytes(name, pos, rddata, len);
        tty->printf("  read %u. bytes:\n ", num);
        for (i = 0; i < num; ++i) { tty->printf(" %02X", rddata[i]); }
        tty->printf("\n");
    }

    tty->printf("\n========================================\n\n");
    return;
}
#endif // TEST_SD



//
// run user command
//
void run_command (char *cmd)
{
    char c;
    uint8_t i, j;
    char *arg;
    uint32_t size;
    static const char timing_mode[][9]  = { "Fastest", "Medium", "RealRX02" };
    static const char  debug_mode[][8]  = { "Off", "Low", "High", "Extreme" };
    static const char access_mode[][4]  = { "R/W", "R/O" };
    static const char  drive_mode[][10] = { "RX01+RX11", "RX01+RX8E", "RX02+any" };
    static const char ext_rx1[] = ".RX1";
    static const char ext_rx2[] = ".RX2";

    // get pointer to next char after 1st space (else NULL if no spaces)
    if ((arg = strchr(cmd, ' ')) != NULL) arg++;
    // set to NULL if arg is a zero length string (ie, line ended with a trailing space)
    if (*arg == 0) arg = NULL;

    // skip to a new line
    tty->printf(F("\n"));

    // parse the command
    switch (toupper(*cmd)) {

        // "0 FILENAME" set unit 0/1 file name
        case '0':
        case '1':
            i = *cmd-'0';
            if (arg) {
                size = sd_get_file_size(arg);
                if (sd_file_ext_matches(arg, ext_rx1) && size != rx_dsk_size(RX_DEN_SD)) {
                    size = sd_set_file_size(arg, rx_dsk_size(RX_DEN_SD), SD_POS_AT_END);
                    tty->printf(F("Updated file: '%s' to %lu. bytes\n"), arg, size);
                } else if (sd_file_ext_matches(arg, ext_rx2) && size != rx_dsk_size(RX_DEN_DD)) {
                    size = sd_set_file_size(arg, rx_dsk_size(RX_DEN_DD), SD_POS_AT_END);
                    tty->printf(F("Updated file: '%s' to %lu. bytes\n"), arg, size);
                }
                tty->printf(F("Setting file[%d]: '%s'\n"), i, rx_unit_file(i, arg));
                size = sd_get_file_size(arg);
                if (size != 0 && size != rx_dsk_size(RX_DEN_SD) && size != rx_dsk_size(RX_DEN_DD)) {
                    tty->printf(F("WARNING: file size not SD or DD ... use E/F command to correct!\n"));
                } else if (size == rx_dsk_size(RX_DEN_DD) && rx_emulation_type() != RX_TYPE_RX02) {
                    tty->printf(F("WARNING: file size DD mounted in mode RX01!\n"));
                }
            } else {
                tty->printf(F("Current file[%d]: '%s'\n"), i, rx_unit_file(i));
            }
            break;

        // "extend FILENAME" extend/create file name as single density sized (but not .RX2 files)
        case 'E':
            if (arg) {
                size = sd_get_file_size(arg);
                if (sd_file_ext_matches(arg, ext_rx2)) {
                    tty->printf(F("Unchanged file: '%s' is %lu. bytes (use F command)\n"), arg, size);
                } else if (size == rx_dsk_size(RX_DEN_SD)) {
                    tty->printf(F("Unchanged file: '%s' is %lu. bytes (SD)\n"), arg, size);
                } else if (size < rx_dsk_size(RX_DEN_SD)) {
                    size = sd_set_file_size(arg, rx_dsk_size(RX_DEN_SD), SD_POS_AT_END);
                    tty->printf(F("Extended file: '%s' to %lu. bytes (SD)\n"), arg, size);
                } else {
                    size = sd_set_file_size(arg, rx_dsk_size(RX_DEN_SD), SD_POS_AT_END);
                    tty->printf(F("Truncated file: '%s' to %lu. bytes (SD)\n"), arg, size);
                }
            }
            break;

        // "full FILENAME" extend/create file name as double density sized (but not .RX1 files)
        case 'F':
            if (arg) {
                size = sd_get_file_size(arg);
                if (sd_file_ext_matches(arg, ext_rx1)) {
                    tty->printf(F("Unchanged file: '%s' is %lu. bytes (use E command)\n"), arg, size);
                } else if (size == rx_dsk_size(RX_DEN_DD)) {
                    tty->printf(F("Unchanged file: '%s' is %lu. bytes (DD)\n"), arg, size);
                } else if (size < rx_dsk_size(RX_DEN_DD)) {
                    size = sd_set_file_size(arg, rx_dsk_size(RX_DEN_DD), SD_POS_AT_END);
                    tty->printf(F("Extended file: '%s' to %lu. bytes (DD)\n"), arg, size);
                } else {
                    size = sd_set_file_size(arg, rx_dsk_size(RX_DEN_DD), SD_POS_AT_END);
                    tty->printf(F("Truncated file: '%s' to %lu. bytes (DD)\n"), arg, size);
                }
            }
            break;

        //  "yes N" set unit N as read-write mode
        case 'Y':
            if (arg && isdigit(c = *arg)) {
                i = c-'0';
                j = rx_unit_mode(i, RX_FILE_READ_WRITE);
                tty->printf(F("Setting file[%d] mode: %s\n"), i, access_mode[j]);
            }
            break;

        //  "no N" set unit N as read-only mode
        case 'N':
            if (arg && isdigit(c = *arg)) {
                i = c-'0';
                j = rx_unit_mode(i, RX_FILE_READ_ONLY);
                tty->printf(F("Setting file[%d] mode: %s\n"), i, access_mode[j]);
            }
            break;

        // "remove FILENAME" remove file name
        case 'R':
            if (arg && sd_remove_file(arg)) {
                tty->printf(F("Removed file: '%s'\n"), arg);
            } else {
                if (arg) tty->printf(F("No such file\n"));
            }
            break;

        // "show" show filename assignments
        case 'S':
            for (i = RX_UNIT_MIN; i <= RX_UNIT_MAX; ++i)
                tty->printf(F("Current file[%d]: '%s' (%s)\n"), i, rx_unit_file(i), access_mode[rx_unit_mode(i)]);
            break;

        // "list" files on the SD card
        case 'L':
            sd_list_files(tty);
            break;

        // "mode N" mode set emulation mode, 0/1/2 as RX01+RX11, RX01+RX8E, RX02+any
        case 'M':
            if (arg && isdigit(c = *arg)) {
                i = rx_emulation_type(c-'0');
                tty->printf(F("Setting emulation mode: %d (%s)\n"), i, drive_mode[i]);
            } else {
                i = rx_emulation_type();
                tty->printf(F("Current emulation type: %d (%s)\n"), i, drive_mode[i]);
            }
            break;

        // "debug N" debug level set, 0/1/2/3
        case 'D':
            if (arg && isdigit(c = *arg)) {
                i = rx_debug(tty, c-'0');
                tty->printf(F("Setting debug mode: %d (%s)\n"), i, debug_mode[i]);
            } else {
                i = rx_debug();
                tty->printf(F("Current debug mode: %d (%s)\n"), i, debug_mode[i]);
            }
            break;

        // "timing N" timing mode set, 0/1/2 as fast/medium/slow
        case 'T':
            if (arg && isdigit(c = *arg)) {
                i = rx_timing_type(c-'0');
                tty->printf(F("Setting timing mode: %d (%s)\n"), i, timing_mode[i]);
            } else {
                i = rx_timing_type();
                tty->printf(F("Current timing mode: %d (%s)\n"), i, timing_mode[i]);
            }
            break;

        // "print" print emulation state
        case 'P':
            rx_print_state(tty);
            break;

        // "init" do an RX emulator initialize
        case 'I':
            tty->printf(F("Sending INIT ...\n"));
            rx_initialize(false);
            tty->printf(F("... INIT complete\n"));
            break;

        // "kill" do an RX emulator reboot and restart
        case 'K':
            tty->printf(F("\n*** Rebooting the emulator ***\n"));
            delay(1000);
            resetFunc();
            tty->printf(F("*** SHOULD NEVER GET HERE***\n"));
            break;

        // "write" write the setup file from the current configuration
        case 'W':
            setup_write(setup_filename);
            break;

#ifdef USE_TIMELIB_H
        // "zap" setup the initial timestamp, as in: Z 2017-03-31 19:30:45
        case 'Z':
            if (arg) {
                // arguments set date and time
                uint16_t yr; uint8_t mo, da, hh, mm, ss;
                // scan a time string
                if (sscanf(arg, "%u-%hhu-%hhu %hhu:%hhu:%hhu", &yr, &mo, &da, &hh, &mm, &ss) == 6) {
                    if (1970 <= yr && yr <= 2099 && 01 <= mo && mo <= 12 && 01 <= da && da <= 31 &&
                        00 <= hh && hh <= 23 && 00 <= mm && mm <= 59 && 00 <= ss && ss <= 59) {
                        // initialize time
                        setTime(hh,mm,ss, da,mo,yr);
                        tty->printf(F("Date/time set!\n"));
                    } else {
                        tty->printf(F("Invalid date/time format!\n"));
                    }
                } else if (sscanf(arg, "%u-%hhu-%hhu %hhu:%hhu", &yr, &mo, &da, &hh, &mm) == 5) {
                    if (1970 <= yr && yr <= 2099 && 01 <= mo && mo <= 12 && 01 <= da && da <= 31 &&
                        00 <= hh && hh <= 23 && 00 <= mm && mm <= 59) {
                        // initialize time
                        setTime(hh,mm,00, da,mo,yr);
                        tty->printf(F("Date/time set!\n"));
                    } else {
                        tty->printf(F("Invalid date/time format!\n"));
                    }
                } else {
                    tty->printf(F("Unrecognized format, use YYYY-MM-DD HH:MM\n"));
                }
            } else {
                // no arguments display date and time
                tty->printf(F("%04d-%02d-%02d %02d:%02d:%02d\n"), year(), month(), day(), hour(), minute(), second());
            }
            break;
#endif // USE_TIMELIB_H

        // "help" or "?"
        case 'H':
        case '?':
            // Note keep any single printf command string at 80 characters maximum
            tty->printf(F("\nCommands available:\n\n"));
            tty->printf(F("  0 FILENAME    -- set unit 0 file to FILENAME; default RX0.DSK\n"));
            tty->printf(F("                   file name 'none' (any case) for no disk present\n"));
            tty->printf(F("  1 FILENAME    -- set unit 1 file to FILENAME; default RX1.DSK\n"));
            tty->printf(F("                   file name 'none' (any case) for no disk present\n"));
            tty->printf(F("  y(es) N       -- set unit N file read-write (default)\n"));
            tty->printf(F("  n(o) N        -- set unit N file read-only\n"));
            tty->printf(F("  m(ode) N      -- set emulation mode, 0=RX01+RX11, 1=RX01+RX8E, "));
            tty->printf(F("2=RX02+any; default 2\n"));
            tty->printf(F("  d(ebug) N     -- debug level, 0=none, 3=max; default 1\n"));
            tty->printf(F("  t(iming) N    -- timing mode, 0=fast, 1=medium, 2=normal; default 0\n"));
            tty->printf(F("                   0 as fast as possible; 2 simulates real RX02 drive\n"));
            tty->printf(F("  r FILENAME    -- remove file FILENAME\n"));
            tty->printf(F("  e FILENAME    -- extend/truncate file FILENAME to single density size\n"));
            tty->printf(F("  f FILENAME    -- extend/truncate file FILENAME to double density size\n"));
            tty->printf(F("  l(ist)        -- list all files on the SD card\n"));
            tty->printf(F("  s(how)        -- show current unit filename assignments\n"));
            tty->printf(F("  p(rint)       -- print full emulation state\n"));
            tty->printf(F("  i(nit)        -- initialize emulator (like unibus INIT)\n"));
            tty->printf(F("  k(ill)        -- kill the emulator (reset and restart, like reset button)\n"));
            tty->printf(F("  w(rite)       -- write current configuration into the SETUP.INI file\n"));
#ifdef USE_TIMELIB_H
            tty->printf(F("  z(ap) STAMP   -- set current timestamp for file access\n"));
            tty->printf(F("                   format is: YYYY-MM-DD HH:MM:SS or YYYY-MM-DD HH:MM\n"));
#endif // USE_TIMELIB_H
            tty->printf(F("  h(elp)        -- display this text\n"));
            tty->printf(F("\nNote: chars in () are optional. Case does not matter.\n"));
            break;

        // unknown command
        default:
            tty->printf(F("?Unknown command?\n"));
            break;

    }

    return;
}



//
// process user input
//
void run_user (char c)
{
    static char cmd[40];
    static uint8_t i = 0;

    // echo non-control characters
    if (!isControl(c)) tty->write(c);

    // dispatch on index
    if (i == 0) {
        // start a command if printing, save
        if (isgraph(c)) cmd[i++] = c;
    } else if (iscntrl(c)) {
        // process control character
        if (c == 'U'-'@') {
            // ^U delete/ignore input
            tty->printf(F("^U\n"));
            i = 0;
        } else if (c == 'M'-'@' || c == 'J'-'@') {
            // CR or LF executes command
            cmd[i] = '\0';
            run_command(cmd);
            i = 0;
        }
    } else {
        // don't save multiple consecutive spaces
        if (isspace(c) && isspace(cmd[i-1])) {
            // skip consecutive spaces
        } else {
            // else just save next character if room
            if (i < sizeof(cmd)-2) cmd[i++] = c;
        }
    }

    return;
}



//
// write setup file from current configuration
//
void setup_write (char *name)
{
    File init;
    uint8_t i;

    // remove current file, if exists
    if (sdcard.exists(name)) sdcard.remove(name);

    // indicate generating file
    tty->printf(F("Generating setup file '%s'\n"), name);

    // open file and write config commands
    init = sdcard.open(name, FILE_WRITE);
    for (i = RX_UNIT_MIN; i <= RX_UNIT_MAX; ++i) {
        init.printf(F("%d %s\n"), i, rx_unit_file(i));
        init.printf(F("%c %d\n"), rx_unit_mode(i) == RX_FILE_READ_ONLY ? 'N' : 'Y', i);
    }
    init.printf(F("D %d\n"), rx_debug());
    init.printf(F("M %d\n"), rx_emulation_type());
    init.printf(F("T %d\n"), rx_timing_type());
    init.printf(F("S\n"));
    init.close();

    return;
}



//
// read setup file and set into current configuration
//
void setup_read (char *name)
{
    File init;

    // check file exists
    if (!sdcard.exists(name)) return;

    // indicate processing file
    tty->printf(F("Processing setup file '%s' ...\n"), name);

    // open file and read config commands
    init = sdcard.open(name, FILE_READ);
    while (init.available()) run_user(init.read());
    init.close();

    // and done
    tty->printf(F("... setup file processing complete!\n\n"));
    return;
}



//
// setup routine runs once at power up
//
void setup (void)
{
    // control/status input/output
    tty->begin(SERIAL_BAUD_RATE, SERIAL_8N2);

    // init LED drivers
    led_initialize();

    // say hello
    tty->printf(F("\nRX02 Emulator %s (IDE %u.%u.%u/gcc %s) - %s - %s\n"),
                VERSION,
                (ARDUINO/10000)%100, (ARDUINO/100)%100, (ARDUINO/1)%100,
                __VERSION__, __DATE__, __TIME__);

    // test LEDs
    led_state(red, on);
    led_state(green, on);
    led_state(yellow, on);
    delay(1000);
    led_state(green, off);
    delay(1000);
    led_state(yellow, off);

#if USE_SD
    // check for SD card
    if (DEBUG_SD) sd_debug(tty, DEBUG_SD);
    if (sd_initialize()) {
        tty->printf(F("Valid MicroSD card detected.\n"));
  #if TEST_SD
        sd_test();
  #endif // TEST_SD
    } else {
        tty->printf(F("No valid MicroSD card detected.\n"));
    }
#endif // USE_SD

#if USE_RX
    // init rx11/211/8e interface
    if (DEBUG_RX) rx_debug(tty, DEBUG_RX);
    rx_initialize(true);
#endif // USE_RX

#if USE_SD
    // initial configuration file ?
    if (sdcard.exists(setup_filename)) {
        // exists, process it
        setup_read(setup_filename);
    } else {
        // does not exist, create it
        setup_write(setup_filename);
    }
#endif // USE_SD

    // done
    tty->printf(F("Initialization complete.\n"));
    return;
}



//
// loop routine runs continuously
//
void loop (void)
{
    // check if user typed a character
    if (tty->available()) run_user(tty->read());

#if USE_RX
    // process RX function
    rx_function();
#endif // USE_RX

    // done
    return;
}



// the end

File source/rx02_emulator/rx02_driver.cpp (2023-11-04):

//
// rx02_driver - Simple :-) RX02 driver
//
// Copyright (c) 2015-2022, Donald N North
//
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
// Except as contained in this notice, the name of Donald N North shall not be
// used in advertising or otherwise to promote the sale, use or other dealings
// in this Software without prior written authorization from Donald N North.
//
// 21 Oct 2013 - donorth - Initial code
// 27 Mar 2016 - donorth - Ported to Arduino from CCS/Microchip
// 23 Sep 2016 - donorth - Added clr_request to end of rx_xmit_es()
// 25 Sep 2016 - donorth - Reworked rx_init_es() to set status function dependent
// 02 Oct 2016 - donorth - RX8E/RX28 mode debug...
// 23 Apr 2020 - donorth - Fixed RX01+RX8E mode to ignore DD mode bit in command word
// 08 Aug 2021 - donorth - Updated _rx_recv_hs()/_rx_xmit_hs() macros to work w/longer cables
// 03 Nov 2023 - thunter0512 - Fixes to allow diagnostic ZRXBF0 RX11+RX01 Functional Diagnostic
//                 to run error free on an 11/34+RX11 configuration:
//                 (1) Added rx_clr_done() in rx_intr_init() to reset DONE asap upon INIT seen
//                 (2) In rx_function() do not overwrite rx.ec with RXERR_SUCCESS when rx.fcn.code is RXFCN_RDERROR
//



//
// includes
//
#include "my_project.h"
#include "led_driver.h"
#include "rx02_driver.h"
#include "sdcard_driver.h"



//
// definitions
//

// options

#define USE_BIT_BUILTINS 0 // use bit builtins BitRead() etc vs use logical bit shift/mask operations

// RXCS control/status bit definitions

#define RXCS_GO         (1<<0)    // GO bit                       (reference only; not used in drive)
#define RXCS_FUNCTION   (7<<1)    // function bitfield            (all)
#define RXCS_UNITSEL    (1<<4)    // unit select                  (all)
#define RXCS_DONE       (1<<5)    // function complete            (reference only; not used in drive)
#define RXCS_INTENB     (1<<6)    // interrupt enable             (reference only; not used in drive)
#define RXCS_8BIT       (1<<6)    // 8b mode                      (RX8E/RX28 ONLY)
#define RXCS_TR         (1<<7)    // transfer request             (reference only; not used in drive)
#define RXCS_MAINT      (1<<7)    // maintenance mode             (RX8E/RX28 ONLY)
#define RXCS_DENSEL     (1<<8)    // density select               (RX211/RX28 w/RX02 ONLY)
#define RXCS_HEADSEL    (1<<9)    // head select                  (RX211/RX28 w/RX03 ONLY)
#define RXCS_NU10      (1<<10)    // not used                     (all)
#define RXCS_RX02      (1<<11)    // RX02 interface               (reference only; not used in drive)
#define RXCS_EXTADDR   (3<<12)    // upper bits of phys address   (reference only; not used in drive)
#define RXCS_INIT      (1<<14)    // initialize RX                (reference only; not used in drive)
#define RXCS_ERROR     (1<<15)    // error flag                   (reference only; not used in drive)

#define RXFCN_FILL        (0)     // fill buffer
#define RXFCN_EMPTY       (1)     // empty buffer
#define RXFCN_WRSECT      (2)     // write sector
#define RXFCN_RDSECT      (3)     // read sector
#define RXFCN_SETMEDIA    (4)     // set media density
#define RXFCN_RDSTAT      (5)     // read status
#define RXFCN_WRDDSECT    (6)     // write deleted data sector
#define RXFCN_RDERROR     (7)     // read error code
#define RXFCN_INIT        (8)     // init done; pseudo function code

// RXES status bit definitions

#define RXES_CRC        (1<<0)    // CRC aka READ error           (all)
#define RXES_SIDRDY     (1<<1)    // side ready                   (RX211/RX28 ONLY)
#define RXES_PERR       (1<<1)    // parity error                 (RX11/RX8E w/RX01 ONLY)
#define RXES_INIT       (1<<2)    // controller init done         (all)
#define RXES_RX02       (1<<3)    // set for RX02 drive           (RX28 w/ RX02 ONLY)
#define RXES_ACLO       (1<<3)    // set for AC low               (RX211 w/RX02 ONLY)
#define RXES_WPERR      (1<<3)    // set for write to WP drive    (RX11/RX8E w/RX01 ONLY)
#define RXES_DENERR     (1<<4)    // density error                (all except RX8E w/RX01)
#define RXES_DRVDEN     (1<<5)    // diskette double density      (all except RX8E w/RX01)
#define RXES_DELDATA    (1<<6)    // deleted data detected        (all)
#define RXES_DRVRDY     (1<<7)    // selected drive ready         (all)
#define RXES_UNITSEL    (1<<8)    // unit selected                (RX211 w/RX02 ONLY)
#define RXES_HEADSEL    (1<<9)    // head selected                (RX211 w/RX03 ONLY
#define RXES_WCOVF     (1<<10)    // word count overflow          (RX211 w/RX02 ONLY)
#define RXES_NXM       (1<<11)    // nonexistent memory           (RX211 w/RX02 reference only; not used in drive)

// RX error codes

#define RXERR_SUCCESS    0000   // success, no error
#define RXERR_DR0INIT    0010   // drive 0 failed to init
#define RXERR_DR1INIT    0020   // drive 1 failed to init
#define RXERR_STEPHOME   0030   // found home when stepping for init (RX01 ONLY)
#define RXERR_TRKERR     0040   // access to track > 76
#define RXERR_TRKFAIL    0050   // track not found
#define RXERR_SELFDIAG   0060   // self diagnostic fail (RX01 ONLY)
#define RXERR_SECFAIL    0070   // sector not found
#define RXERR_WRITEWP    0100   // write to a WP drive
#define RXERR_SEPFAIL    0110   // no SEP clock in 40us
#define RXERR_PREFAIL    0120   // preamble not found
#define RXERR_IDMFAIL    0130   // ID mark not found
#define RXERR_CRCHEAD    0140   // CRC error on a header (RX01 ONLY)
#define RXERR_TRKCMP     0150   // header track miscompare
#define RXERR_IDMTRYS    0160   // too many tries for IDAM
#define RXERR_DAMFAIL    0170   // data AM not found
#define RXERR_CRCERR     0200   // CRC error on read
#define RXERR_PERR       0210   // parity error on word from i/f to controller (RX01 ONLY)
#define RXERR_RWFAIL     0220   // r/w failed maint test (RX02 ONLY)
#define RXERR_WCOVF      0230   // word count overflow (RX02 ONLY)
#define RXERR_DENERR     0240   // density error (RX02 ONLY)
#define RXERR_KEYERR     0250   // wrong key word for set density (RX02 ONLY)

// macros

// rx interface outputs set/clr
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

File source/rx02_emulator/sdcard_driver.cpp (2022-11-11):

//
// sdcard_driver - SD card Fat filesystem access routines
//
// Copyright (c) 2015-2022, Donald N North
//
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
// Except as contained in this notice, the name of Donald N North shall not be
// used in advertising or otherwise to promote the sale, use or other dealings
// in this Software without prior written authorization from Donald N North.
//
// 24 Aug 2016 - donorth - Initial code
//



//
// includes
//
#include "my_project.h"
#include "sdcard_driver.h"



// PRIVATE PRIVATE PRIVATE PRIVATE PRIVATE PRIVATE PRIVATE PRIVATE PRIVATE
// PRIVATE PRIVATE PRIVATE PRIVATE PRIVATE PRIVATE PRIVATE PRIVATE PRIVATE
// PRIVATE PRIVATE PRIVATE PRIVATE PRIVATE PRIVATE PRIVATE PRIVATE PRIVATE



//
// private data
//
static HardwareSerial *debugPort = NULL; // debug serial output

static uint8_t debugLevel = 0; // debug level, 0=NONE, higher for more

static File sdfile; // SD card file data structure

static uint8_t initOk = FALSE; // set to TRUE on initialize OK



#ifdef USE_TIMELIB_H
//
// date/time callback function
//
void dateTime (uint16_t *dateptr, uint16_t *timeptr)
{
    // get current time
    time_t t = now();

    // return date using FAT_DATE(yyyy,mm,dd) macro to format fields
    *dateptr = FAT_DATE(year(t), month(t), day(t));

    // return time using FAT_TIME(hh,mm,ss) macro to format fields
    *timeptr = FAT_TIME(hour(t), minute(t), second(t));

    // and done
    return;
}
#endif // USE_TIMELIB_H



// PUBLIC PUBLIC PUBLIC PUBLIC PUBLIC PUBLIC PUBLIC PUBLIC PUBLIC PUBLIC
// PUBLIC PUBLIC PUBLIC PUBLIC PUBLIC PUBLIC PUBLIC PUBLIC PUBLIC PUBLIC
// PUBLIC PUBLIC PUBLIC PUBLIC PUBLIC PUBLIC PUBLIC PUBLIC PUBLIC PUBLIC



//
// public data
//

SdFat sdcard; // SD card filesystem data structure



//
// initialize the SDcard subsystem
//
uint8_t sd_initialize (void)
{
    // configure pins
    pinMode(PIN_SD_CD, INPUT);
    pinMode(PIN_SD_MISO, INPUT);
    pinMode(PIN_SD_MOSI, OUTPUT);
    pinMode(PIN_SD_SCK, OUTPUT);
    pinMode(PIN_SD_CS_L, OUTPUT);

    // set default values
    digitalWrite(PIN_SD_MOSI, HIGH);
    digitalWrite(PIN_SD_SCK, HIGH);
    digitalWrite(PIN_SD_CS_L, HIGH);

    // start out not ok
    initOk = FALSE;

    // check for card detect
    if (!digitalRead(PIN_SD_CD)) return initOk;

    // init card, check for success
    if (!sdcard.begin(PIN_SD_CS_L, SPI_FULL_SPEED)) { sdcard.initErrorHalt(); return initOk; }

    // some card parameters
    uint8_t ctype = sdcard.card()->type();
#if SD_FAT_VERSION <= 20007
    uint32_t csize = ((sdcard.card()->cardSize()/1024L)*512L)/1024L;
#else
    uint32_t csize = ((sdcard.card()->sectorCount()/1024L)*512L)/1024L;
#endif
    if (debugLevel) {
        debugPort->printf(F("SD: libVersion=%d.%d.%d\n"), SD_FAT_VERSION/10000, (SD_FAT_VERSION/100)%100, SD_FAT_VERSION%100);
        debugPort->printf(F("SD: cardType=SD%d\n"), ctype);
        debugPort->printf(F("SD: cardSize=%luMB\n"), csize);
    }

#if SD_FAT_VERSION < 20000
    // check card is open - it should be FAT16 or FAT32
    if (!sdcard.vwd()->isOpen()) return initOk;
#endif

    // some volume parameters
    uint8_t vtype = sdcard.vol()->fatType();
#if SD_FAT_VERSION <= 20007
    uint32_t vbpc = sdcard.vol()->blocksPerCluster()*512L;
#else
    uint32_t vbpc = sdcard.vol()->bytesPerCluster();
#endif
    uint32_t vucc = sdcard.vol()->clusterCount();
    uint32_t vsize = (vbpc/1024L)*(vucc/1024L);
    if (debugLevel) {
        debugPort->printf(F("SD: volType=FAT%d\n"), vtype);
        debugPort->printf(F("SD: volBytesPerCluster=%lu\n"), vbpc);
        debugPort->printf(F("SD: volClusterCount=%lu\n"), vucc);
        debugPort->printf(F("SD: volSizeBytes=%luMB\n"), vsize);
    }

#ifdef USE_TIMELIB_H
    // set date time callback function
    SdFile::dateTimeCallback(dateTime);
#endif // USE_TIMELIB_H

    // success!
    initOk = TRUE;

    // list files
    sd_list_files(debugPort);

    // and done
    return initOk;
}



//
// setup the SDcard subsystem debug port
//
void sd_debug (HardwareSerial *serialPort, uint8_t level)
{
    // setup which serial port to use
    debugPort = serialPort;

    // and the debug level
    debugLevel = level;

    // and done
    return;
}



//
// list files on the SDcard
//
void sd_list_files (HardwareSerial *port)
{
    if (initOk) sdcard.ls(port, LS_DATE | LS_SIZE | LS_R);
    return;
}



//
// remove a file on the SDcard
//
uint8_t sd_remove_file (char *name)
{
    if (!initOk) return FALSE;

    if (sdcard.exists(name)) return sdcard.remove(name);

    return FALSE;
}



//
// check that file extension matches supplied string, return true/false
//
uint8_t sd_file_ext_matches (char *name, const char *ext)
{
    // get ptr to the last filename dot, or NULL
    char *ptr = strrchr(name, '.');

    // if no extension, return false; else return TRUE if extension matches string
    return ptr == NULL ? FALSE : (strcasecmp(ptr, ext) == 0 ? TRUE : FALSE);
}



//
// read bytes from an sdcard file
//
uint16_t sd_read_bytes (char *name, uint32_t pos, uint8_t *buf, uint16_t len)
{
    uint16_t num;

    // error if not setup
    if (!initOk) return 0;

    // close existing file, if open
    if (sdfile.isOpen()) sdfile.close();

    // open current file
    sdfile = sdcard.open(name, FILE_READ);

    // seek to required position
    if (sdfile.seek(pos) == false) { sdfile.close(); return 0; }

    // read requested number of bytes
    num = sdfile.read(buf, len);

    // close the file, done for now
    sdfile.close();

    // and return number of bytes read
    return num;
}
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

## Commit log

2016-10-22 Limit help command printf strings to 80 characters or less (standard buffer size).
2016-10-24 Added Y/N commands to menu to set units read-write or read-only. Commands are added to SETUP.INI file so are remembered across power cycles.
2016-10-24 Documentation correction; fix display of file access mode in printout.
    [rx02_emulator.ino]
2016-10-24 Minor update to error code for write to write protected units.
    [rx02_driver.cpp]
2016-10-28 Change RUN signal trigger from interrupt driven to polled (5-10% better performance).
2016-11-09 Update handling of existing SDcard files that are not exactly SD size (256,256 bytes) or DD size (512,512 byyes). Previous v1.4 code would format/init these files, overwriting data. Now v1.5 code wil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
2016-11-14 Add warning messages when mounting non SD or DD files on units; or when mounting DD sized files when in RX01 mode.
2016-12-05 Added processing of .RX1/.RX2 file extensions for SD/DD media detection. Updated readme; fixed a couple of typos.
    [rx02_emulator.ino, sdcard_driver.cpp]
2017-06-28 Fix handling of special filename NONE for unmounted unit.
    [rx02_driver.cpp, rx02_emulator.ino, sdcard_driver.cpp]
2017-11-01 restructure files to source directory; add documentation and disk images
    [rx02_emulator_BOM.csv]
2017-11-01 broke out gerber files into a subdirectory
    [rx02_emulator.drl, rx02_emulator.gbl, rx02_emulator.gbo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]
2017-11-18 added picture of assembled v4 2n7k board
2018-09-12 updated readme with Arduino program file path
2018-12-22 Minor syntax update for v1.8.8 Arduino IDE
2018-12-27 Change all line endings to strict cr/lf from lf, for Arduino IDE 1.8.8 compatibility
2019-03-17 Updated .csv BOM to add DigiKey part numbers
    [rx02_emulator_BOM.csv]
2019-04-10 updated BOM part HCT14 to AHCT14
    [rx02_emulator_BOM.csv]
2019-08-07 Update 40P header qty from 4 to 3
    [rx02_emulator_BOM.csv]
2020-04-24 Fixed RX01+RX8E mode to ignore DD mode bit in command word
    [rx02_driver.cpp, rx02_emulator.ino]
2020-04-24 Updated README.md file with current bootup display
2021-06-22 Updated .csv BOM with SparkFun part number, added SparkFun microSD schematic pdf
    [rx02_emulator_BOM.csv]
2021-08-09 Updated data shift timing macros to allow for longer interface cable.
2022-07-17 add LED test at startup
2022-07-20 debug data printout for v2 SDcard library (cosmetic change)
2022-10-23 updated BOM to indicate P1,P5,P6 can be NOSTUFF
    [rx02_emulator_BOM.csv]
2022-10-24 update P2,P3 quantity in BOM, add Px callouts to rx02_emulator_pcb_v4rev2_2n7k.pdf document
    [rx02_emulator_BOM.csv]
2022-10-24 add more callouts to PCB image
2022-11-01 updated bom files with recommended assembly order column
    [rx02_emulator_BOM.csv]
2022-11-01 updated some BOM part numbers, revised assembly order
    [rx02_emulator_BOM.csv]
2022-11-03 updated Z command date/time set to have seconds be optional; updated LED test
2022-11-03 reset version to 1.98
    [rx02_emulator.ino]
2022-11-12 update pcb documentation files
    [rx02_emulator.drl, rx02_emulator.gbl, rx02_emulator.gbo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]
2022-11-14 updated PCB directory structure, added files for v5 SMT board
    [rx02_emulator.gbl, rx02_emulator.gbo, rx02_emulator.gbs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]
2022-11-14 rename jlcpcb pick& place file correctly
    [rx02_emulator_jlcpcb_pick_and_place.csv]
2023-03-09 updated README Arduino IDE usage, some formatting changes, no functional difference
2023-05-05 updated BOM notes, added RT11.RX1 file
    [rx02_emulator_BOM.csv]
2023-07-12 added k(ill) command to menu to allow full reboot/reset of emulator
    [rx02_emulator.ino]
2023-11-01 update for RX11 ErrCode register read failure in ZRXBF0 diagnostic
    [rx02_driver.cpp, rx02_emulator.ino]
2023-11-04 updates per thunter0512 for 11/34+RX11 diagnostic INIT/DONE fix
    [rx02_driver.cpp, rx02_emulator.ino]
